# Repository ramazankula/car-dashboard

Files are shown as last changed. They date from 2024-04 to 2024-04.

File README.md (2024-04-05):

# Renault Megane 2 Dashboard Panel Prototype for Vehicle Simulator
In this project, a clone of Renault Megane 2 car dashboard panel is designed specially for a vehicle simulator project. It was designed to be compatible with vehicel simulation software.

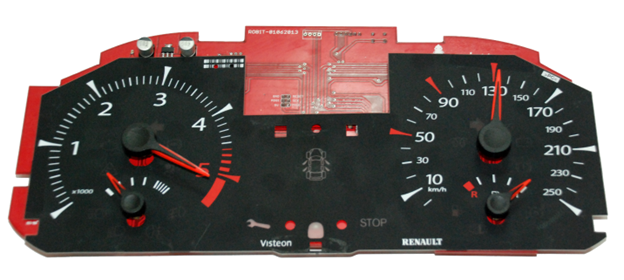
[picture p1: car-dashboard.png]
Renault Megane 2 Dashboard


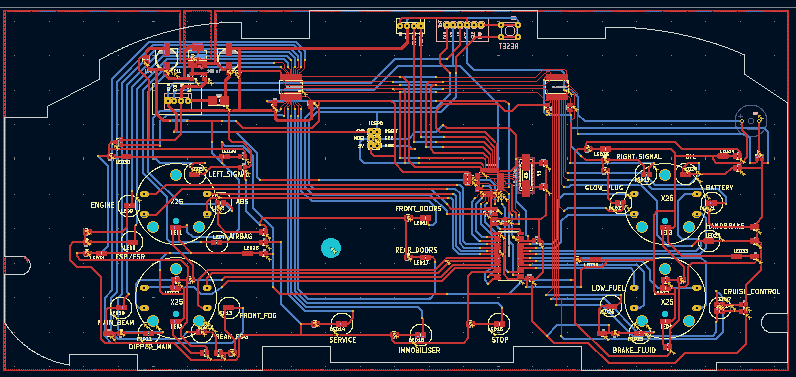
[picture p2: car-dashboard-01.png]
Renault Megane 2 Dashboard


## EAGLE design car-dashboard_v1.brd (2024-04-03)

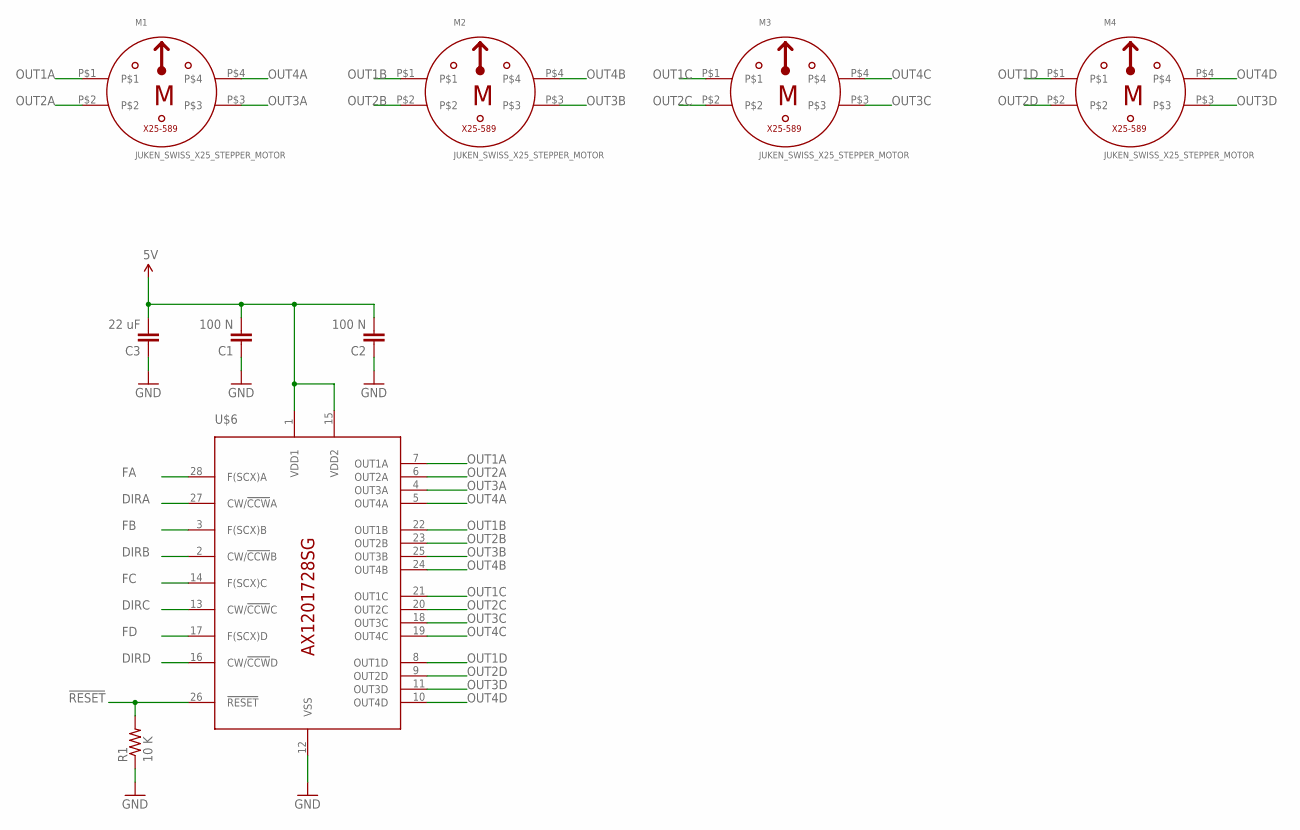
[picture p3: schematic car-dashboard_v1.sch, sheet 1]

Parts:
C1, C2: 100 N; C0805
C3: 22 uF; C0805
M1, M2, M3, M4: JUKEN_SWISS_X25_STEPPER_MOTOR; X25_STEPPER_MOTOR
R1: 10 K; 0805
U$6: AX1201728SG-X25_DRIVER; SOL-28

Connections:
5V: C1.2, C2.2, C3.2, U$6.1 (VDD1), U$6.15 (VDD2); also elsewhere on the board
!RESET: R1.2, U$6.26 (!RESET); also elsewhere on the board
DIRA: U$6.27 (CW/!CCW!A); also elsewhere on the board
DIRB: U$6.2 (CW/!CCW!B); also elsewhere on the board
DIRC: U$6.13 (CW/!CCW!C); also elsewhere on the board
DIRD: U$6.16 (CW/!CCW!D); also elsewhere on the board
FA: U$6.28 (F(SCX)A); also elsewhere on the board
FB: U$6.3 (F(SCX)B); also elsewhere on the board
FC: U$6.14 (F(SCX)C); also elsewhere on the board
FD: U$6.17 (F(SCX)D); also elsewhere on the board
GND: C1.1, C2.1, C3.1, R1.1, U$6.12 (VSS); also elsewhere on the board
OUT1A: M1.P$1, U$6.7 (OUT1A)
OUT1B: M2.P$1, U$6.22 (OUT1B)
OUT1C: M3.P$1, U$6.21 (OUT1C)
OUT1D: M4.P$1, U$6.8 (OUT1D)
OUT2A: M1.P$2, U$6.6 (OUT2A)
OUT2B: M2.P$2, U$6.23 (OUT2B)
OUT2C: M3.P$2, U$6.20 (OUT2C)
OUT2D: M4.P$2, U$6.9 (OUT2D)
OUT3A: M1.P$3, U$6.4 (OUT3A)
OUT3B: M2.P$3, U$6.25 (OUT3B)
OUT3C: M3.P$3, U$6.18 (OUT3C)
OUT3D: M4.P$3, U$6.11 (OUT3D)
OUT4A: M1.P$4, U$6.5 (OUT4A)
OUT4B: M2.P$4, U$6.24 (OUT4B)
OUT4C: M3.P$4, U$6.19 (OUT4C)
OUT4D: M4.P$4, U$6.10 (OUT4D)

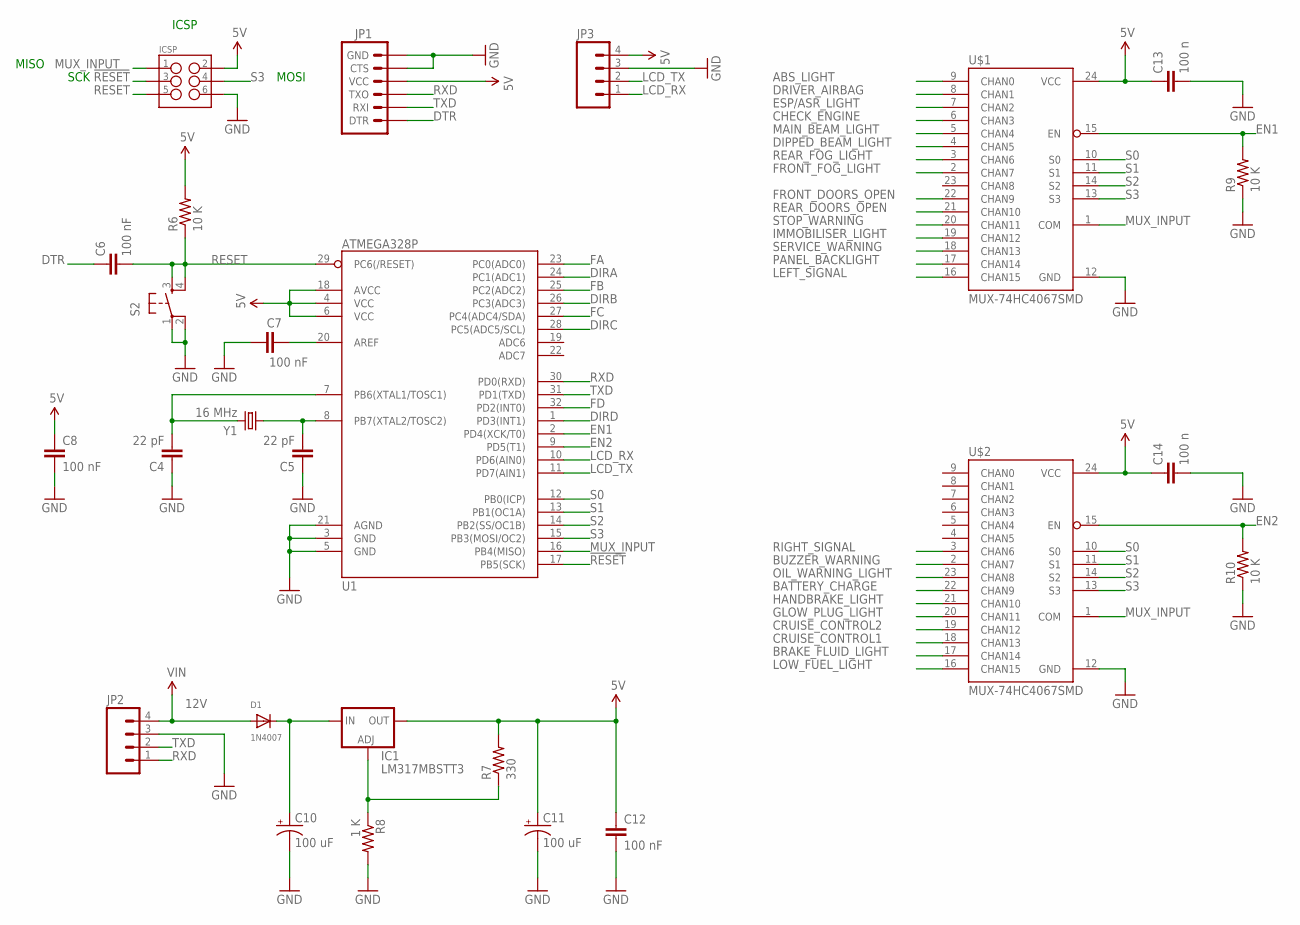
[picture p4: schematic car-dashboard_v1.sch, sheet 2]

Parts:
C4, C5: 22 pF; C0805
C6, C7, C8, C12: 100 nF; C0805
C10, C11: 100 uF; PANASONIC_F
C13, C14: 100 n; C0805
D1: 1N4007; SMADIODE
IC1: LM317MBSTT3; SOT223
ICSP: M03X22X3_SILK_SM; 2X3
JP1: ARDUINO_SERIAL_PROGRAMPTH; 1X06
JP2, JP3: M04POLAR; MOLEX-1X4
R6, R9, R10: 10 K; R0805
R7: 330; R0805
R8: 1 K; R0805
S2: TAC_SWITCHPTH; TACTILE-PTH
U1: ATMEGA328P; TQFP32-08
U$1, U$2: MUX-74HC4067SMD; SSOP24
Y1: 16 MHz; HC49UP

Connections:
5V: C8.1, C11.+, C12.1, C13.1, C14.1, IC1.4 (OUT), ICSP.2, JP1.4 (VCC), JP3.4, R6.2, R7.2, U1.4 (VCC), U1.6 (VCC), U1.18 (AVCC), U$1.24 (VCC), U$2.24 (VCC); also elsewhere on the board
12V: D1.A, JP2.4
!RESET: ICSP.3, U1.17 (PB5(SCK)); also elsewhere on the board
ABS_LIGHT: U$1.9 (CHAN0); also elsewhere on the board
BATTERY_CHARGE: U$2.22 (CHAN9); also elsewhere on the board
BRAKE_FLUID_LIGHT: U$2.17 (CHAN14); also elsewhere on the board
BUZZER_WARNING: U$2.2 (CHAN7); also elsewhere on the board
CHECK_ENGINE: U$1.6 (CHAN3); also elsewhere on the board
CRUISE_CONTROL1: U$2.18 (CHAN13); also elsewhere on the board
CRUISE_CONTROL2: U$2.19 (CHAN12); also elsewhere on the board
DIPPED_BEAM_LIGHT: U$1.4 (CHAN5); also elsewhere on the board
DIRA: U1.24 (PC1(ADC1)); also elsewhere on the board
DIRB: U1.26 (PC3(ADC3)); also elsewhere on the board
DIRC: U1.28 (PC5(ADC5/SCL)); also elsewhere on the board
DIRD: U1.1 (PD3(INT1)); also elsewhere on the board
DRIVER_AIRBAG: U$1.8 (CHAN1); also elsewhere on the board
DTR: C6.1, JP1.1 (DTR)
EN1: R9.2, U1.2 (PD4(XCK/T0)), U$1.15 (EN)
EN2: R10.2, U1.9 (PD5(T1)), U$2.15 (EN)
ESP/ASR_LIGHT: U$1.7 (CHAN2); also elsewhere on the board
FA: U1.23 (PC0(ADC0)); also elsewhere on the board
FB: U1.25 (PC2(ADC2)); also elsewhere on the board
FC: U1.27 (PC4(ADC4/SDA)); also elsewhere on the board
FD: U1.32 (PD2(INT0)); also elsewhere on the board
FRONT_DOORS_OPEN: U$1.22 (CHAN9); also elsewhere on the board
FRONT_FOG_LIGHT: U$1.2 (CHAN7); also elsewhere on the board
GLOW_PLUG_LIGHT: U$2.20 (CHAN11); also elsewhere on the board
GND: C4.1, C5.1, C7.1, C8.2, C10.-, C11.-, C12.2, C13.2, C14.2, ICSP.6, JP1.5 (CTS), JP1.6 (GND), JP2.3, JP3.3, R8.2, R9.1, R10.1, S2.1, S2.2, U1.3 (GND), U1.5 (GND), U1.21 (AGND), U$1.12 (GND), U$2.12 (GND); also elsewhere on the board
HANDBRAKE_LIGHT: U$2.21 (CHAN10); also elsewhere on the board
IMMOBILISER_LIGHT: U$1.19 (CHAN12); also elsewhere on the board
LCD_RX: JP3.1, U1.10 (PD6(AIN0))
LCD_TX: JP3.2, U1.11 (PD7(AIN1))
LEFT_SIGNAL: U$1.16 (CHAN15); also elsewhere on the board
LOW_FUEL_LIGHT: U$2.16 (CHAN15); also elsewhere on the board
MAIN_BEAM_LIGHT: U$1.5 (CHAN4); also elsewhere on the board
MUX_INPUT: ICSP.1, U1.16 (PB4(MISO)), U$1.1 (COM), U$2.1 (COM)
unnamed: C4.2, U1.7 (PB6(XTAL1/TOSC1)), Y1.2
unnamed: C5.2, U1.8 (PB7(XTAL2/TOSC2)), Y1.1
unnamed: C10.+, D1.C, IC1.3 (IN)
unnamed: C7.2, U1.20 (AREF)
unnamed: IC1.1 (ADJ), R7.1, R8.1
OIL_WARNING_LIGHT: U$2.23 (CHAN8); also elsewhere on the board
PANEL_BACKLIGHT: U$1.17 (CHAN14); also elsewhere on the board
REAR_DOORS_OPEN: U$1.21 (CHAN10); also elsewhere on the board
REAR_FOG_LIGHT: U$1.3 (CHAN6); also elsewhere on the board
RESET: C6.2, ICSP.5, R6.1, S2.3, S2.4, U1.29 (PC6(/RESET))
RIGHT_SIGNAL: U$2.3 (CHAN6); also elsewhere on the board
RXD: JP1.3 (TXO), JP2.1, U1.30 (PD0(RXD))
S0: U1.12 (PB0(ICP)), U$1.10 (S0), U$2.10 (S0)
S1: U1.13 (PB1(OC1A)), U$1.11 (S1), U$2.11 (S1)
S2: U1.14 (PB2(SS/OC1B)), U$1.14 (S2), U$2.14 (S2)
S3: ICSP.4, U1.15 (PB3(MOSI/OC2)), U$1.13 (S3), U$2.13 (S3)
SERVICE_WARNING: U$1.18 (CHAN13); also elsewhere on the board
STOP_WARNING: U$1.20 (CHAN11); also elsewhere on the board
TXD: JP1.2 (RXI), JP2.2, U1.31 (PD1(TXD))

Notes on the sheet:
SCK
MISO
MOSI
ICSP

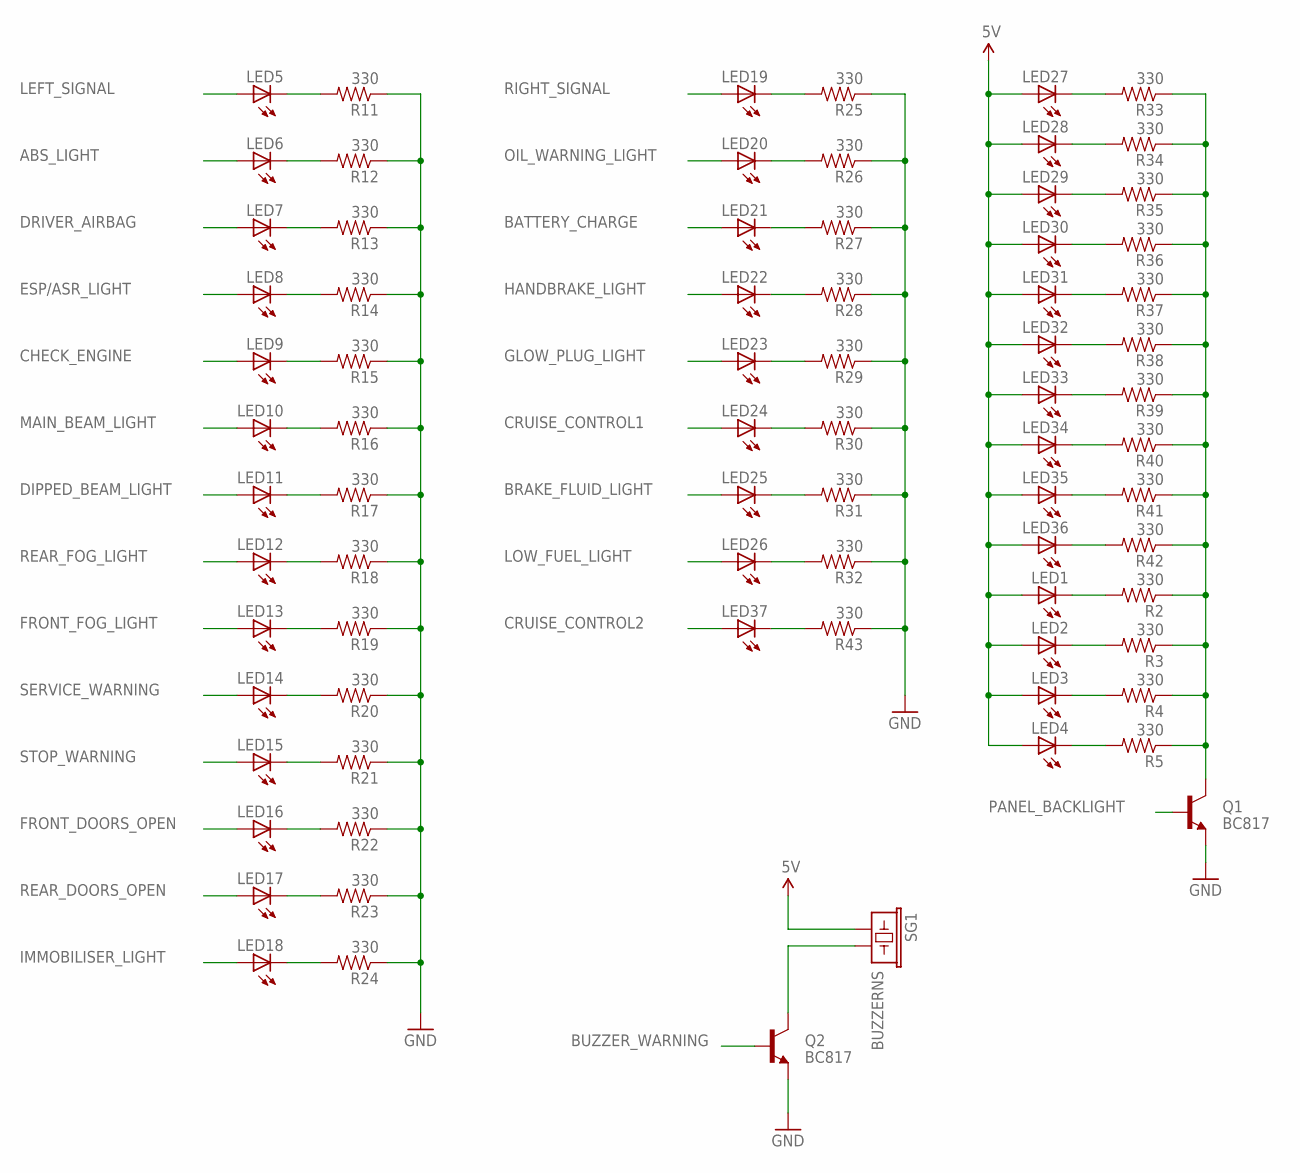
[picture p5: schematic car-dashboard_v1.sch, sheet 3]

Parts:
LED1, LED2, LED3, LED4, LED5, LED6, LED7, LED8, LED9, LED10, LED11, LED12, LED13, LED14, LED15, LED16, LED17, LED18, LED19, LED20, LED21, LED22, LED23, LED24, LED25, LED26, LED27, LED28, LED29, LED30, LED31, LED32, LED33, LED34, LED35, LED36, LED37: LEDCHIPLED_0805; CHIPLED_0805
Q1, Q2: BC817; SOT23-3
R2, R3, R4, R5, R11, R12, R13, R14, R15, R16, R17, R18, R19, R20, R21, R22, R23, R24, R25, R26, R27, R28, R29, R30, R31, R32, R33, R34, R35, R36, R37, R38, R39, R40, R41, R42, R43: 330; 0805
SG1: BUZZERNS; BUZZER-12MM-NS

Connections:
5V: LED1.A, LED2.A, LED3.A, LED4.A, LED27.A, LED28.A, LED29.A, LED30.A, LED31.A, LED32.A, LED33.A, LED34.A, LED35.A, LED36.A, SG1.+ (1); also elsewhere on the board
ABS_LIGHT: LED6.A; also elsewhere on the board
BATTERY_CHARGE: LED21.A; also elsewhere on the board
BRAKE_FLUID_LIGHT: LED25.A; also elsewhere on the board
BUZZER_WARNING: Q2.1 (B); also elsewhere on the board
CHECK_ENGINE: LED9.A; also elsewhere on the board
CRUISE_CONTROL1: LED24.A; also elsewhere on the board
CRUISE_CONTROL2: LED37.A; also elsewhere on the board
DIPPED_BEAM_LIGHT: LED11.A; also elsewhere on the board
DRIVER_AIRBAG: LED7.A; also elsewhere on the board
ESP/ASR_LIGHT: LED8.A; also elsewhere on the board
FRONT_DOORS_OPEN: LED16.A; also elsewhere on the board
FRONT_FOG_LIGHT: LED13.A; also elsewhere on the board
GLOW_PLUG_LIGHT: LED23.A; also elsewhere on the board
GND: Q1.2 (E), Q2.2 (E), R11.1, R12.1, R13.1, R14.1, R15.1, R16.1, R17.1, R18.1, R19.1, R20.1, R21.1, R22.1, R23.1, R24.1, R25.1, R26.1, R27.1, R28.1, R29.1, R30.1, R31.1, R32.1, R43.1; also elsewhere on the board
HANDBRAKE_LIGHT: LED22.A; also elsewhere on the board
IMMOBILISER_LIGHT: LED18.A; also elsewhere on the board
LEFT_SIGNAL: LED5.A; also elsewhere on the board
LOW_FUEL_LIGHT: LED26.A; also elsewhere on the board
MAIN_BEAM_LIGHT: LED10.A; also elsewhere on the board
unnamed: LED1.C, R2.2
unnamed: LED2.C, R3.2
unnamed: LED3.C, R4.2
unnamed: LED4.C, R5.2
unnamed: LED5.C, R11.2
unnamed: LED6.C, R12.2
unnamed: LED7.C, R13.2
unnamed: LED8.C, R14.2
unnamed: LED9.C, R15.2
unnamed: LED10.C, R16.2
unnamed: LED11.C, R17.2
unnamed: LED12.C, R18.2
unnamed: LED37.C, R43.2
unnamed: LED13.C, R19.2
unnamed: LED14.C, R20.2
unnamed: LED15.C, R21.2
unnamed: LED16.C, R22.2
unnamed: LED17.C, R23.2
unnamed: LED18.C, R24.2
unnamed: LED19.C, R25.2
unnamed: LED20.C, R26.2
unnamed: LED21.C, R27.2
unnamed: LED22.C, R28.2
unnamed: LED23.C, R29.2
unnamed: LED24.C, R30.2
unnamed: LED25.C, R31.2
unnamed: LED26.C, R32.2
unnamed: LED27.C, R33.2
unnamed: LED28.C, R34.2
unnamed: LED29.C, R35.2
unnamed: LED30.C, R36.2
unnamed: LED31.C, R37.2
unnamed: Q1.3 (C), R2.1, R3.1, R4.1, R5.1, R33.1, R34.1, R35.1, R36.1, R37.1, R38.1, R39.1, R40.1, R41.1, R42.1
unnamed: LED32.C, R38.2
unnamed: LED33.C, R39.2
unnamed: LED34.C, R40.2
unnamed: LED35.C, R41.2
unnamed: LED36.C, R42.2
unnamed: Q2.3 (C), SG1.- (2)
OIL_WARNING_LIGHT: LED20.A; also elsewhere on the board
PANEL_BACKLIGHT: Q1.1 (B); also elsewhere on the board
REAR_DOORS_OPEN: LED17.A; also elsewhere on the board
REAR_FOG_LIGHT: LED12.A; also elsewhere on the board
RIGHT_SIGNAL: LED19.A; also elsewhere on the board
SERVICE_WARNING: LED14.A; also elsewhere on the board
STOP_WARNING: LED15.A; also elsewhere on the board

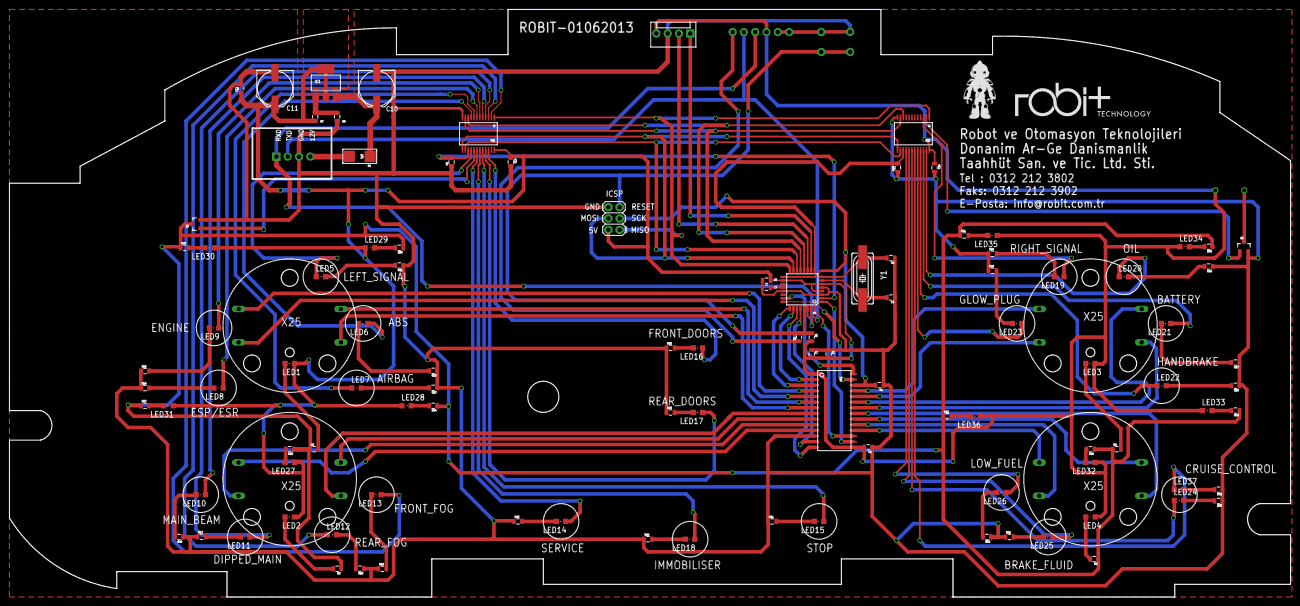
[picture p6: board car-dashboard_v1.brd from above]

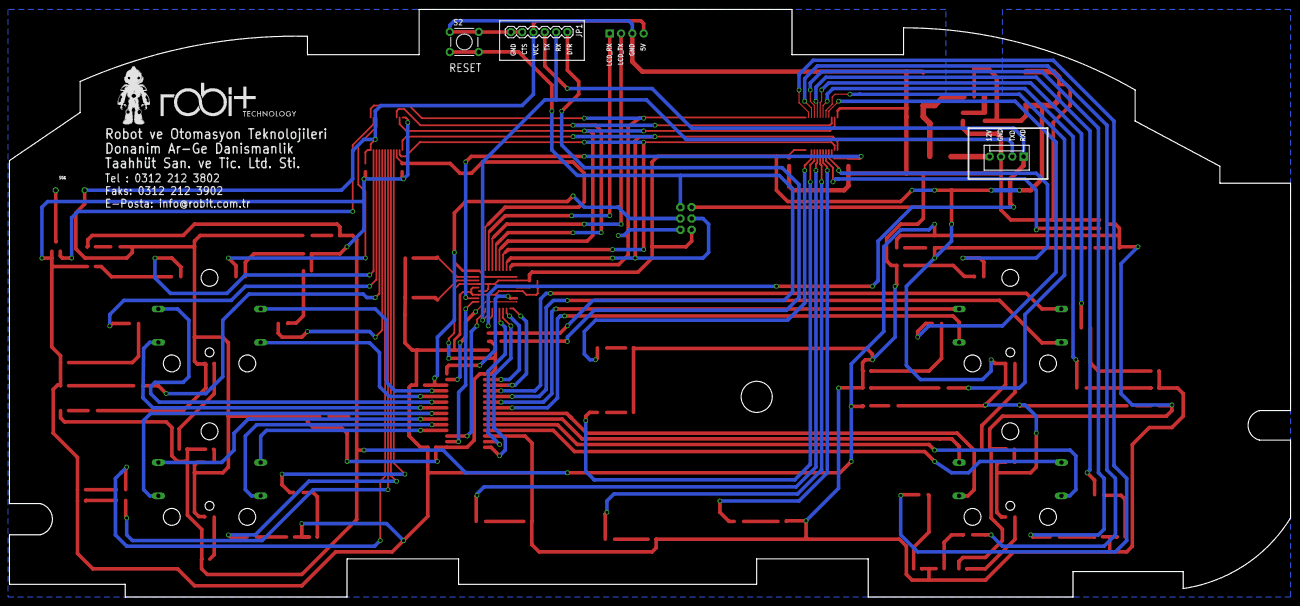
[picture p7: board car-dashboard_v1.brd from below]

Board: 2 copper layers, 288.0 x 132.1 mm, 116 parts (5 on the bottom side), 110 nets.

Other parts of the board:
U$3: ROBIT_ROBOT_BP
U$4: ROBIT_ROBOT
U$5, U$7: ROBIT_LOGO

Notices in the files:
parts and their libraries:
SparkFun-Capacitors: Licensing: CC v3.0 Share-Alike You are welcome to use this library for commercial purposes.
